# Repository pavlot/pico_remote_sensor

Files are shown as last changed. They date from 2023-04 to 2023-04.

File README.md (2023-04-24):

# RPi Pico remote sensor shield
[Raspberry Pi Pico](https://www.raspberrypi.com/products/raspberry-pi-pico/) shield for sensors and wireless data transfer with [RFM75 2.4GHz radiomodule](https://www.hoperf.com/modules/2.4g/RFM75.html)

Board


## Firmware installation
This shield has example firmware to transmit and reaceive data.
Before any scripts uploaded [Micropython must be installed](https://micropython.org/download/rp2-pico/) to you RPi pico board

### Install from github
If you wand just to run firmware and check how it works, the easiest way is to install it as package
You will need [mpremote](https://docs.micropython.org/en/latest/reference/mpremote.html) tool to perform this operation.
After you board connected to usb and MicroPython installed execute:
```bash
mpremote.py mip install https://raw.githubusercontent.com/pavlot/pico_remote_sensor/main/firmware/package.json
```
This will install firmware package and required dependencies to your board.

This firmware shipped with two modules: transmitter and receiver.

Open Micropython REPL session with  
```bash
mpremote.py
```
and execute
```python
from firmware import receiver
```
On console you should see something like:
```
INFO:root:TX part started
INFO:root:----  Starting module initialisation ------
INFO:root:Is RFMx chip connected: True
INFO:root:Chip id: 63000000
INFO:root:RF channel set to 4
INFO:root:LNA gain set to high
INFO:root:Data rate is: 250ksps
INFO:root:Adress width binary value: 11
INFO:root:Pipe 0 enabled
INFO:root:RX_Pipe 0 address set to 1122332211
INFO:root:PipeAddr after set: 1122332211
INFO:root:PipeAddr: 1122332211
INFO:root:Pipe 0 RX payload width is 5
INFO:root:Auto acknowledge disabled
INFO:root:CRC encoding scheme 2 bytes
INFO:root:CRC enabled
INFO:root:RFx module power up
INFO:root:----  Module initialisation done ------
INFO:root:----  Starting main receive loop ------
```
it means that rx part is ready to receive data. Default implementation will output all receivet data as hex values to INFO logger, e.g.
```
INFO:root:Data received: cafeb0ba01
```

Same procedure for transmitter, inside REPL session:
```
from firmware import transmitter
```

Transmitter expects SHT30 sensor to be connected to I2C0 bus and continuosly read it's values sending them to the air.
Also transmitted values logged to the INFO logger

### Autostart
If you want that transmitter or receiver start on board startup you have to create main.py in the root foldef of board filesystem.

To simplify this procedure install_* modules shipped with firmware.

For example, if you want to make trasmitter: inside mpremote REPL console execute
```
from firmware import install_transmitter
```
and reboot with `Ctrl+]` or switch-off/switch-on your device. This will make it transmitting sensor data without any human interaction.

Now you can poweron it from USB charger and place at bathroom, data will be transfered automatically.

### Development
If you want to implement own logic, change configuration or write everything from scratch you can clone this repository and mount source directory like
```shell
mpremote.py mount src
``` 
All changes you will do will be immidiately available on your board.

Only remember to perform Soft reboot befor re-importing any modules

This firmware depends on [pyRFTdi](https://github.com/pavlot/pyrftdi) module. This dependencies could be installed like:
```
mpremote mip install https://raw.githubusercontent.com/pavlot/pyrftdi/RPPico/package.json
```

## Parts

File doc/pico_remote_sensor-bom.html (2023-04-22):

 | KiBot Bill of Materials
 | Schematic: pico_remote_sensor Variant: default Revision: Date: 2023-04-22_11-45-25 KiCad Version: 6.0.2+dfsg-1 | Component Groups: 6 Component Count: 11 (per PCB) Fitted Components: 11 (per PCB) Number of PCBs: 1 Total Components: 11 (for 1 PCBs)
Row | Description | Part | References | Value | Footprint | Quantity Per PCB | Status | Datasheet
1 | Unpolarized capacitor | C | C1 | C | C_1206_3216Metric_Pad1.33x1.80mm_HandSolder | 1 |  | ~
2 | Generic connector, double row, 02x20, counter clockwise pin numbering scheme (similar to DIP packge numbering), script generated (kicad-library-utils/schlib/autogen/connector/) | Conn_02x20_Counter_Clockwise | J1 J2 | Conn_02x20_Counter_Clockwise | PinHeader_2x20_P2.54mm_Vertical | 2 |  | ~
3 | Generic connector, single row, 01x04, script generated (kicad-library-utils/schlib/autogen/connector/) | Conn_01x04_Male | J_I2C_L0 J_I2C_L1 | Conn_01x04_Male | PinHeader_1x04_P2.00mm_Vertical | 2 |  | ~
4 | Resistor | R | R1 R2 R3 R4 | 4,7K | R_1206_3216Metric_Pad1.30x1.75mm_HandSolder | 4 |  | ~
5 |  | Pico | U1 | Pico | RPi_Pico_SMD_TH | 1
6 |  | RFM75 | U2 | RFM75 | RFM75 | 1
Color reference:
KiCad Fields (default)
Generated Fields
User Fields
Empty Fields

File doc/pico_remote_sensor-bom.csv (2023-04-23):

Row | Part | References | Value | Footprint | Quantity Per PCB
1 | C | C1 | C | C_1206_3216Metric_Pad1.33x1.80mm_HandSolder | 1
2 | Conn_02x20_Counter_Clockwise | J1 J2 | Conn_02x20_Counter_Clockwise | PinHeader_2x20_P2.54mm_Vertical | 2
3 | Conn_01x04_Male | J_I2C_L0 J_I2C_L1 | Conn_01x04_Male | PinHeader_1x04_P2.00mm_Vertical | 2
4 | R | R1 R2 R3 R4 | 4,7K | R_1206_3216Metric_Pad1.30x1.75mm_HandSolder | 4
5 | Pico | U1 | Pico | RPi_Pico_SMD_TH | 1
6 | RFM75 | U2 | RFM75 | RFM75 | 1

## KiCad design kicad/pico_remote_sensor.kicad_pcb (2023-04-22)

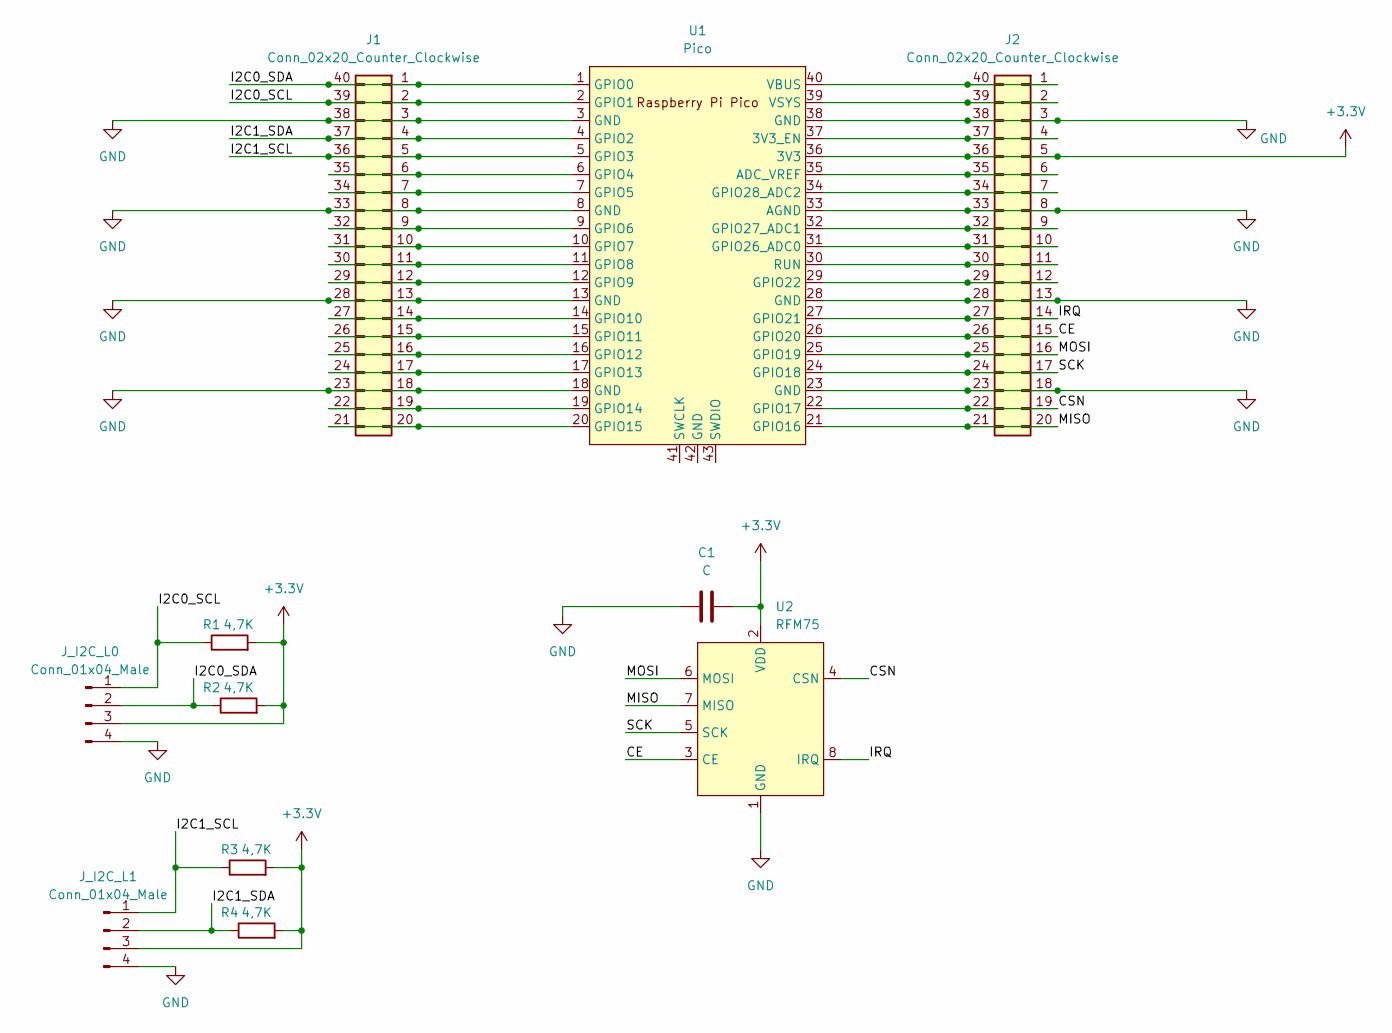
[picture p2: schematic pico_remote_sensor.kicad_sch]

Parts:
C1: C; C_1206_3216Metric_Pad1.33x1.80mm_HandSolder
J1, J2: Conn_02x20_Counter_Clockwise; PinHeader_2x20_P2.54mm_Vertical
J_I2C_L0, J_I2C_L1: Conn_01x04_Male; PinHeader_1x04_P2.00mm_Vertical
R1, R2, R3, R4: 4,7K; R_1206_3216Metric_Pad1.30x1.75mm_HandSolder
U1: Pico; RPi_Pico_SMD_TH
U2: RFM75

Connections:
+3V3: C1.1, J2.5, J2.36, J_I2C_L0.3, J_I2C_L1.3, R1.2, R2.2, R3.2, R4.2, U1.36 (3V3), U2.2 (VDD)
/CE: J2.15, J2.26, U1.26 (GPIO20), U2.3 (CE)
/CSN: J2.19, J2.22, U1.22 (GPIO17), U2.4 (CSN)
/I2C0_SCL: J1.2, J1.39, J_I2C_L0.1, R1.1, U1.2 (GPIO1)
/I2C0_SDA: J1.1, J1.40, J_I2C_L0.2, R2.1, U1.1 (GPIO0)
/I2C1_SCL: J1.5, J1.36, J_I2C_L1.1, R3.1, U1.5 (GPIO3)
/I2C1_SDA: J1.4, J1.37, J_I2C_L1.2, R4.1, U1.4 (GPIO2)
/IRQ: J2.14, J2.27, U1.27 (GPIO21), U2.8 (IRQ)
/MISO: J2.20, J2.21, U1.21 (GPIO16), U2.7 (MISO)
/MOSI: J2.16, J2.25, U1.25 (GPIO19), U2.6 (MOSI)
/SCK: J2.17, J2.24, U1.24 (GPIO18), U2.5 (SCK)
GND: C1.2, J1.3, J1.8, J1.13, J1.18, J1.23, J1.28, J1.33, J1.38, J2.3, J2.8, J2.13, J2.18, J2.23, J2.28, J2.33, J2.38, J_I2C_L0.4, J_I2C_L1.4, U1.3 (GND), U1.8 (GND), U1.13 (GND), U1.18 (GND), U1.23 (GND), U1.28 (GND), U1.33 (AGND), U1.38 (GND), U2.1 (GND)
unnamed: J1.6, J1.35, U1.6 (GPIO4)
unnamed: J1.7, J1.34, U1.7 (GPIO5)
unnamed: J1.9, J1.32, U1.9 (GPIO6)
unnamed: J1.10, J1.31, U1.10 (GPIO7)
unnamed: J1.11, J1.30, U1.11 (GPIO8)
unnamed: J1.12, J1.29, U1.12 (GPIO9)
unnamed: J1.14, J1.27, U1.14 (GPIO10)
unnamed: J1.15, J1.26, U1.15 (GPIO11)
unnamed: J1.16, J1.25, U1.16 (GPIO12)
unnamed: J1.17, J1.24, U1.17 (GPIO13)
unnamed: J1.19, J1.22, U1.19 (GPIO14)
unnamed: J1.20, J1.21, U1.20 (GPIO15)
unnamed: J2.12, J2.29, U1.29 (GPIO22)
unnamed: J2.11, J2.30, U1.30 (RUN)
unnamed: J2.10, J2.31, U1.31 (GPIO26_ADC0)
unnamed: J2.9, J2.32, U1.32 (GPIO27_ADC1)
unnamed: J2.7, J2.34, U1.34 (GPIO28_ADC2)
unnamed: J2.6, J2.35, U1.35 (ADC_VREF)
unnamed: J2.4, J2.37, U1.37 (3V3_EN)
unnamed: J2.2, J2.39, U1.39 (VSYS)
unnamed: J2.1, J2.40, U1.40 (VBUS)

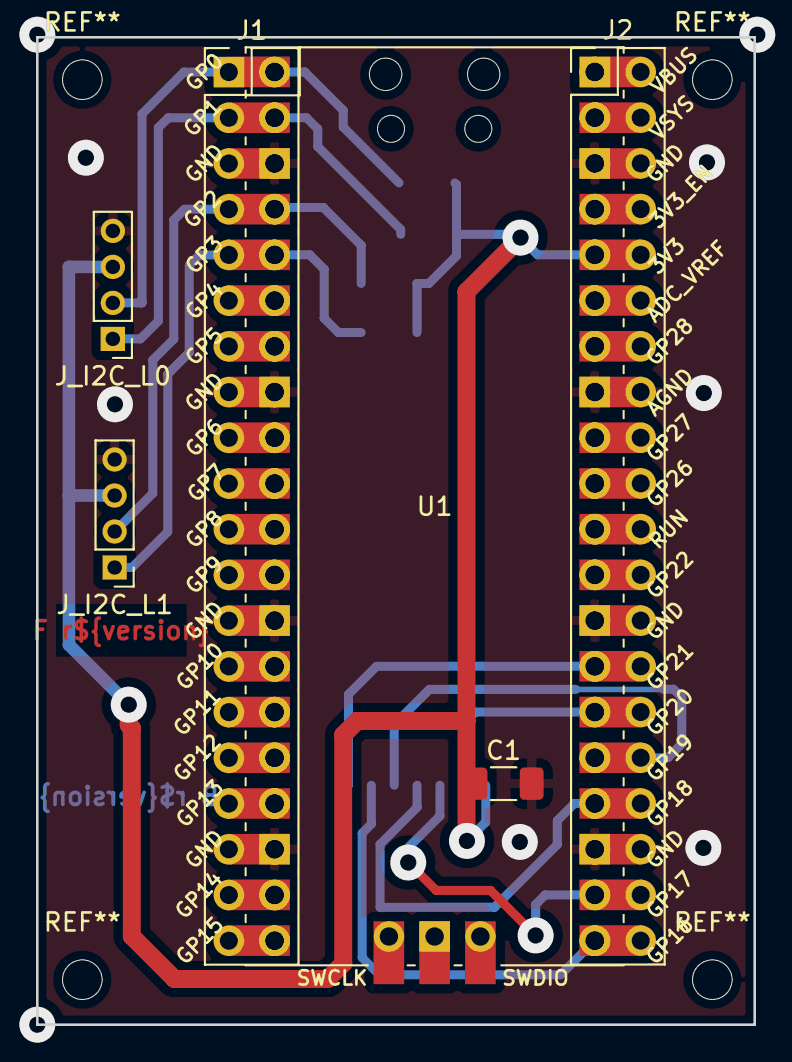
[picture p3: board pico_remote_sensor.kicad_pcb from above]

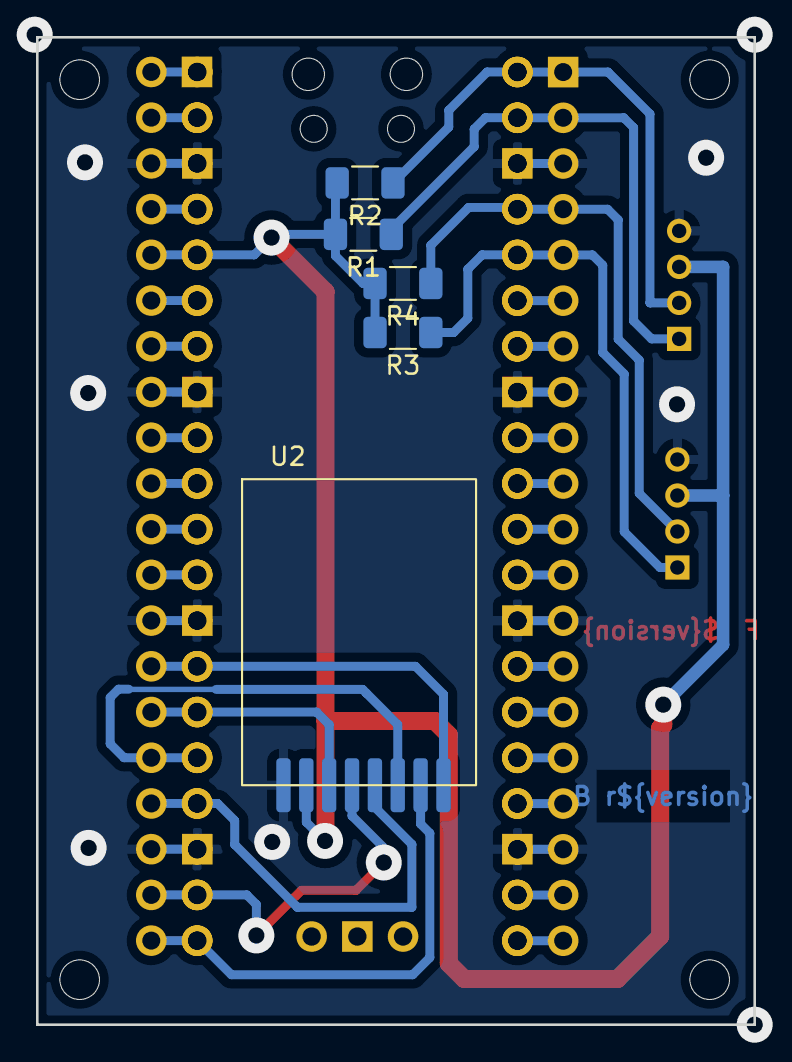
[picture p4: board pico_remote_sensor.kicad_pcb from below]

Board: 2 copper layers, 39.9 x 54.9 mm, 11 parts (5 on the bottom side), 33 nets.

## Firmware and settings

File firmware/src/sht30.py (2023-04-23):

from machine import SoftI2C, Pin
import time

__version__ = '0.2.1'
__author__ = 'Roberto Sánchez'
__license__ = "Apache License 2.0. https://www.apache.org/licenses/LICENSE-2.0"

# I2C address B 0x45 ADDR (pin 2) connected to VDD
DEFAULT_I2C_ADDRESS = 0x45

class SHT30():
    """
    SHT30 sensor driver in pure python based on I2C bus
    
    References: 
    * https://www.sensirion.com/fileadmin/user_upload/customers/sensirion/Dokumente/2_Humidity_Sensors/Sensirion_Humidity_Sensors_SHT3x_Datasheet_digital.pdf
    * https://www.wemos.cc/sites/default/files/2016-11/SHT30-DIS_datasheet.pdf
    * https://github.com/wemos/WEMOS_SHT3x_Arduino_Library
    * https://www.sensirion.com/fileadmin/user_upload/customers/sensirion/Dokumente/11_Sample_Codes_Software/Humidity_Sensors/Sensirion_Humidity_Sensors_SHT3x_Sample_Code_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
    """
    POLYNOMIAL = 0x131  # P(x) = x^8 + x^5 + x^4 + 1 = 100110001

    ALERT_PENDING_MASK = 0x8000 # 15
    HEATER_MASK = 0x2000        # 13
    RH_ALERT_MASK = 0x0800		# 11
    T_ALERT_MASK = 0x0400		# 10
    RESET_MASK = 0x0010	        # 4
    CMD_STATUS_MASK = 0x0002	# 1
    WRITE_STATUS_MASK = 0x0001	# 0

    # MSB = 0x2C LSB = 0x06 Repeatability = High, Clock stretching = enabled
    MEASURE_CMD = b'\x2C\x10'
    STATUS_CMD = b'\xF3\x2D'
    RESET_CMD = b'\x30\xA2'
    CLEAR_STATUS_CMD = b'\x30\x41'
    ENABLE_HEATER_CMD = b'\x30\x6D'
    DISABLE_HEATER_CMD = b'\x30\x66'

    def __init__(self, scl_pin=5, sda_pin=4, delta_temp = 0, delta_hum = 0, i2c_address=DEFAULT_I2C_ADDRESS):
        self.i2c = SoftI2C(scl=Pin(scl_pin), sda=Pin(sda_pin))
        self.i2c_addr = i2c_address
        self.set_delta(delta_temp, delta_hum)
        time.sleep_ms(50)
    
    def init(self, scl_pin=5, sda_pin=4):
        """
        Init the I2C bus using the new pin values
        """
        self.i2c.init(scl=Pin(scl_pin), sda=Pin(sda_pin))
    
    def is_present(self):
        """
        Return true if the sensor is correctly conneced, False otherwise
        """
        return self.i2c_addr in self.i2c.scan()
    
    def set_delta(self, delta_temp = 0, delta_hum = 0):
        """
        Apply a delta value on the future measurements of temperature and/or humidity
        The units are Celsius for temperature and percent for humidity (can be negative values)
        """
        self.delta_temp = delta_temp
        self.delta_hum = delta_hum
    
    def _check_crc(self, data):
        # calculates 8-Bit checksum with given polynomial
        crc = 0xFF
        
        for b in data[:-1]:
            crc ^= b;
            for _ in range(8, 0, -1):
                if crc & 0x80:
                    crc = (crc << 1) ^ SHT30.POLYNOMIAL;
                else:
                    crc <<= 1
        crc_to_check = data[-1]
        return crc_to_check == crc
    
    def send_cmd(self, cmd_request, response_size=6, read_delay_ms=100):
        """
        Send a command to the sensor and read (optionally) the response
        The responsed data is validated by CRC
        """
        try:
            self.i2c.start(); 
            self.i2c.writeto(self.i2c_addr, cmd_request); 
            if not response_size:
                self.i2c.stop(); 	
                return
            time.sleep_ms(read_delay_ms)
            data = self.i2c.readfrom(self.i2c_addr, response_size) 
            self.i2c.stop(); 
            for i in range(response_size//3):
                if not self._check_crc(data[i*3:(i+1)*3]): # pos 2 and 5 are CRC
                    raise SHT30Error(SHT30Error.CRC_ERROR)
            if data == bytearray(response_size):
                raise SHT30Error(SHT30Error.DATA_ERROR)
            return data
        except OSError as ex:
            if 'I2C' in ex.args[0]:
                print(ex)
                raise SHT30Error(SHT30Error.BUS_ERROR)
            raise ex

    def clear_status(self):
        """
        Clear the status register
        """
        return self.send_cmd(SHT30.CLEAR_STATUS_CMD, None); 

    def reset(self):
        """
        Send a soft-reset to the sensor
        """
        return self.send_cmd(SHT30.RESET_CMD, None); 

    def status(self, raw=False):
        """
        Get the sensor status register. 
        It returns a int value or the bytearray(3) if raw==True
        """
        data = self.send_cmd(SHT30.STATUS_CMD, 3, read_delay_ms=20); 

        if raw:
            return data

        status_register = data[0] << 8 | data[1]
        return status_register
    
    def measure(self, raw=False):
        """
        If raw==True returns a bytearrya(6) with sensor direct measurement otherwise
        It gets the temperature (T) and humidity (RH) measurement and return them.
        
        The units are Celsius and percent
        """
        data = self.send_cmd(SHT30.MEASURE_CMD, 6); 

        if raw:
            return data

        t_celsius = (((data[0] << 8 |  data[1]) * 175) / 0xFFFF) - 45 + self.delta_temp;
        rh = (((data[3] << 8 | data[4]) * 100.0) / 0xFFFF) + self.delta_hum;
        return t_celsius, rh

    def measure_int(self, raw=False):
        """
        Get the temperature (T) and humidity (RH) measurement using integers.
        If raw==True returns a bytearrya(6) with sensor direct measurement otherwise
        It returns a tuple with 4 values: T integer, T decimal, H integer, H decimal
        For instance to return T=24.0512 and RH= 34.662 This method will return
        (24, 5, 34, 66) Only 2 decimal digits are returned, .05 becomes 5
        Delta values are not applied in this method
        The units are Celsius and percent.
        """
        data = self.send_cmd(SHT30.MEASURE_CMD, 6); 
        if raw: 
            return data
        aux = (data[0] << 8 | data[1]) * 175
        t_int = (aux // 0xffff) - 45;
        t_dec = (aux % 0xffff * 100) // 0xffff
        aux = (data[3] << 8 | data[4]) * 100
        h_int = aux // 0xffff
        h_dec = (aux % 0xffff * 100) // 0xffff
        return t_int, t_dec, h_int, h_dec


class SHT30Error(Exception):
    """
    Custom exception for errors on sensor management
    """
    BUS_ERROR = 0x01 
    DATA_ERROR = 0x02
    CRC_ERROR = 0x03

    def __init__(self, error_code=None):
        self.error_code = error_code
        super().__init__(self.get_message())
    
    def get_message(self):
        if self.error_code == SHT30Error.BUS_ERROR:
            return "Bus error"
        elif self.error_code == SHT30Error.DATA_ERROR:
            return "Data error"
        elif self.error_code == SHT30Error.CRC_ERROR:
            return "CRC error"
        else:
            return "Unknown error"

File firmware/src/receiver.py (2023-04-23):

import logging
from time import sleep
from machine import SPI, Pin
from pyRFTdi.spi.SpiControllerRPPico import SpiControllerRPPico
from struct import *
from pyRFTdi.Rfm75Enums import Rfm75AddressWidth, Rfm75CRCLen, Rfm75TxPower
from pyRFTdi.Rfm75RegisterController import Rfm75RegisterController
from pyRFTdi.Rfm75Controller import FtdiRfm75Controller
from pyRFTdi.Rfm75Registers import Rfm75Register, Rfm75Registers

logging.basicConfig(level=logging.INFO)
logging.info("TX part started")

##################################################################################################
# Config
##################################################################################################

FTDI_URL = 'ftdi://ftdi:232h:555552/1'  # Url for ftdi chip, used to control RX
CE_PIN = 7                              # FTDI pin used to as CE for RFM device

PIPE_NO = 0                             # Pipe number used to receive data
ADDR_WIDTH = Rfm75AddressWidth.ADDR_5   # How many bytes used for address
PIPE_ADDR = b'\x11\x22\x33\x22\x11'       # Addres where to transmit
RF_CHANNEL = 0x04                       # Operating Rf Channel
DATA_RATE = '250ksps'                   # Transfer speed
PAYLOAD_SIZE = 0x05                     # Static payload size up to 32b

##################################################################################################
# End of config
##################################################################################################
spi = SPI(0, baudrate=1000000, sck=Pin(18), mosi=Pin(19), miso=Pin(16))           # Create SPI peripheral 0 at frequency of 400kHz.
                                        # Depending on the use case, extra parameters may be required
                                        # to select the bus characteristics and/or pins to use.
cs_pin = Pin(17, mode=Pin.OUT, value=0)      # Create chip-select on pin 4.
ce_pin = Pin(20, mode=Pin.OUT, value=0)
spi_controller = SpiControllerRPPico(spi, cs_pin)

reg_controller = Rfm75RegisterController(spi_controller)

logging.info("----  Starting module initialisation ------")

controller = FtdiRfm75Controller(spi_controller, ce_pin, reg_controller)

if(not controller.is_connected()):
    logging.error("RFMx controller not found, exit")
    exit(1)

logging.info("Chip id: {}".format(controller.get_chip_id().hex()))
controller.config_ctrl.reset_config()
controller.config_ctrl.set_rf_channel(RF_CHANNEL)
controller.config_ctrl.set_lna_gain_high()
controller.config_ctrl.chip_init(DATA_RATE)

controller.config_ctrl.disable_dynamic_payload()
controller.config_ctrl.disable_dynamic_acknowledge()

controller.activate_features()

controller.config_ctrl.set_address_width(ADDR_WIDTH)

# Configure PIPE
controller.config_ctrl.pipe_ctrl.enable_pipe(PIPE_NO)
logging.info("PipeAddr after set: {}".format(controller.config_ctrl.pipe_ctrl.set_rx_pipe_address(PIPE_NO, PIPE_ADDR).hex()))
logging.info("PipeAddr: {}".format(controller.config_ctrl.pipe_ctrl.get_rx_pipe_address(PIPE_NO).hex()))
controller.config_ctrl.pipe_ctrl.set_rx_pipe_payload_width(PIPE_NO, PAYLOAD_SIZE)
controller.config_ctrl.pipe_ctrl.disable_auto_acknowledge()

controller.config_ctrl.crc_ctrl.set_crc_len(Rfm75CRCLen.CRC_2)
controller.config_ctrl.crc_ctrl.enable_crc()
#controller.config_ctrl.crc_ctrl.disable_crc()

controller.set_mode_rx()

controller.power_up()
controller.ce_on()

logging.info("----  Module initialisation done ------")
logging.info("----  Starting main receive loop ------")
try:
    while(1):
        if(controller.is_rx_data_ready()):
            logging.info("Data received: {}".format(controller.read_rx_payload(5).hex()))
            controller.unset_rx_data_ready()

except KeyboardInterrupt:
    logging.info("----  Keyboard interrupt, shutdown ------")
    controller.ce_off()
    controller.power_down()

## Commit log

2023-04-22 Schematics imported
    [pico_remote_sensor.kicad_pcb, pico_remote_sensor.kicad_sch]
2023-04-22 Photoresisting production added
    [pico_remote_sensor-drill.drl]
2023-04-22 Board versions added
    [pico_remote_sensor.kicad_pcb]
2023-04-22 Drilling implemented
    [pico_remote_sensor-drill.drl]
